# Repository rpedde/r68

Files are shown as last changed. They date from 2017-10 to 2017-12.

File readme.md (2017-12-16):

# r68 std #

This a 68% board, like a tada or sabre.

This supports two layouts:

[Compat](https://goo.gl/bRej9A): This format requires a 1.75u right shift, but retains 1.25u FN keys ([json data](compat.json))
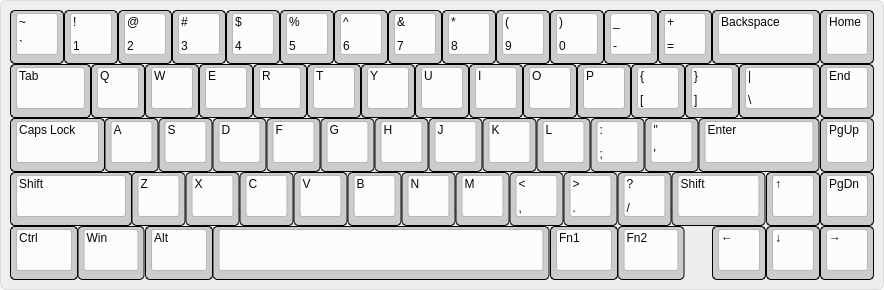
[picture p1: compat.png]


[Narrow](https://goo.gl/9U5wPm): This keeps more meta keys to the right of the space bar, but requires 1u FN keys ([json data](narrow.json))
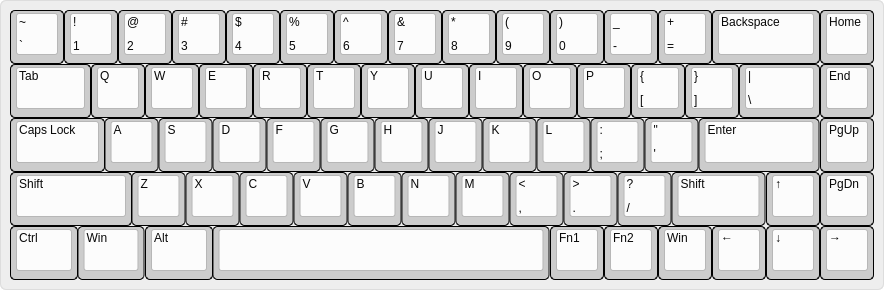
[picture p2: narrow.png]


## Hardware Revisions/Errata ##

* 1.0: Initial version (bad right arrow, not recommended) [gerbers](https://storage.googleapis.com/rpedde-public-gerbers/r68-r1.0.zip)
* 1.1: Fix right arrow, change (ground short on C14) [gerbers](https://storage.googleapis.com/rpedde-public-gerbers/r68-r1.1.zip)
* 1.2: Repour ground (ordered from easyeda, verified working) [gerbers](https://storage.googleapis.com/rpedde-public-gerbers/r68-r1.2.zip)

## License ##

This work is Copyright 2017 Ron Pedde and distributed under the term of the GNU General Public License (version 2 or later).

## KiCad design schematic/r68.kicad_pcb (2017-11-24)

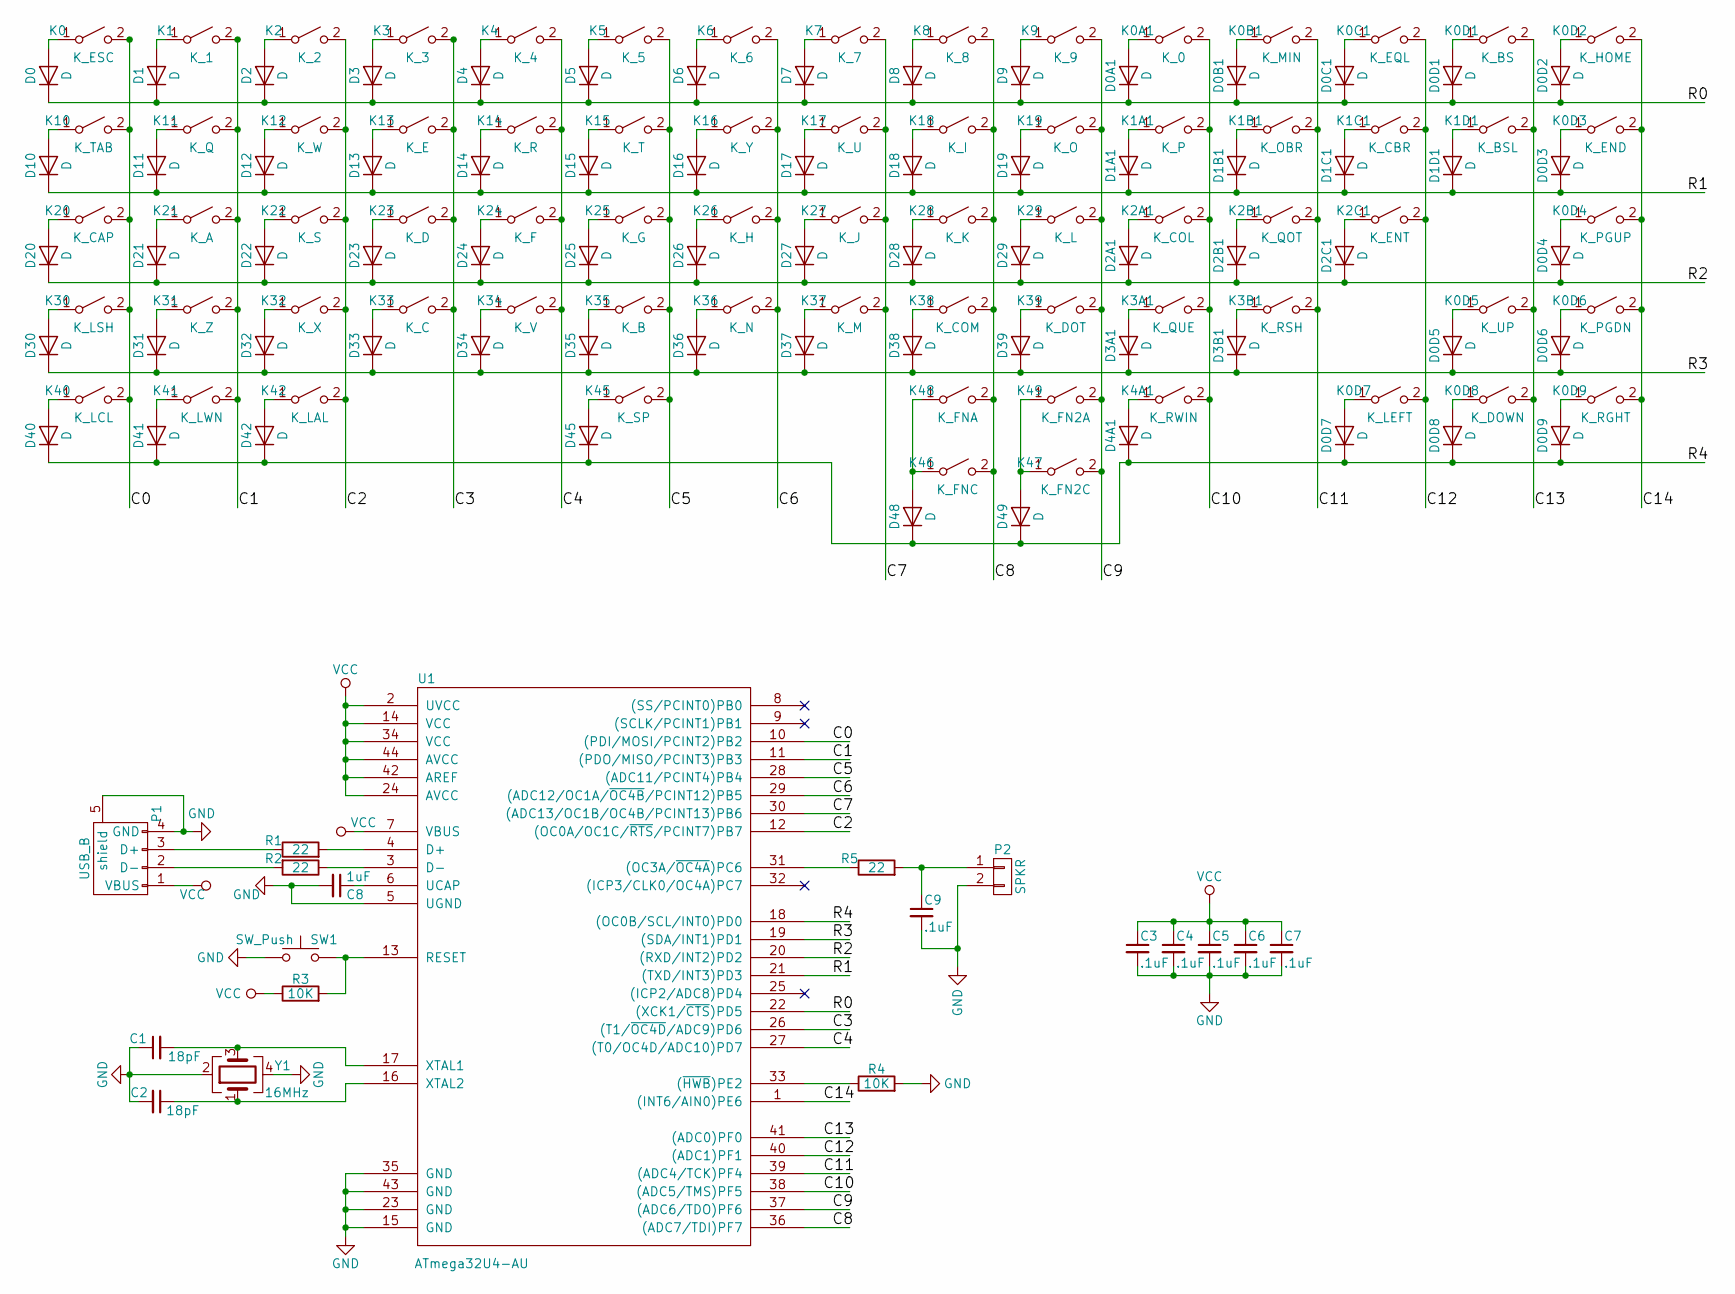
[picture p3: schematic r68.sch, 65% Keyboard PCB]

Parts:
C1, C2: 18pF; C_0805
C3, C4, C5, C6, C7, C9: .1uF; C_0805
C8: 1uF; C_0805
D0, D0A1, D0B1, D0C1, D0D1, D0D2, D0D3, D0D4, D0D5, D0D6, D0D7, D0D8, D0D9, D1, D1A1, D1B1, D1C1, D1D1, D2, D2A1, D2B1, D2C1, D3, D3A1, D3B1, D4, D4A1, D5, D6, D7, D8, D9, D10, D11, D12, D13, D14, D15, D16, D17, D18, D19, D20, D21, D22, D23, D24, D25, D26, D27, D28, D29, D30, D31, D32, D33, D34, D35, D36, D37, D38, D39, D40, D41, D42, D45, D48, D49: D; D_0805
K0: K_ESC; CHERRY_PCB_100H
K0A1: K_0; CHERRY_PCB_100H
K0B1: K_MIN; CHERRY_PCB_100H
K0C1: K_EQL; CHERRY_PCB_100H
K0D1: K_BS; CHERRY_PCB_200H
K0D2: K_HOME; CHERRY_PCB_100H
K0D3: K_END; CHERRY_PCB_100H
K0D4: K_PGUP; CHERRY_PCB_100H
K0D5: K_UP; CHERRY_PCB_100H
K0D6: K_PGDN; CHERRY_PCB_100H
K0D7: K_LEFT; CHERRY_PCB_100H
K0D8: K_DOWN; CHERRY_PCB_100H
K0D9: K_RGHT; CHERRY_PCB_100H
K1: K_1; CHERRY_PCB_100H
K1A1: K_P; CHERRY_PCB_100H
K1B1: K_OBR; CHERRY_PCB_100H
K1C1: K_CBR; CHERRY_PCB_100H
K1D1: K_BSL; CHERRY_PCB_150H
K2: K_2; CHERRY_PCB_100H
K2A1: K_COL; CHERRY_PCB_100H
K2B1: K_QOT; CHERRY_PCB_100H
K2C1: K_ENT; CHERRY_PCB_225H
K3: K_3; CHERRY_PCB_100H
K3A1: K_QUE; CHERRY_PCB_100H
K3B1: K_RSH; CHERRY_PCB_175H
K4: K_4; CHERRY_PCB_100H
K4A1: K_RWIN; CHERRY_PCB_100H
K5: K_5; CHERRY_PCB_100H
K6: K_6; CHERRY_PCB_100H
K7: K_7; CHERRY_PCB_100H
K8: K_8; CHERRY_PCB_100H
K9: K_9; CHERRY_PCB_100H
K10: K_TAB; CHERRY_PCB_150H
K11: K_Q; CHERRY_PCB_100H
K12: K_W; CHERRY_PCB_100H
K13: K_E; CHERRY_PCB_100H
K14: K_R; CHERRY_PCB_100H
K15: K_T; CHERRY_PCB_100H
K16: K_Y; CHERRY_PCB_100H
K17: K_U; CHERRY_PCB_100H
K18: K_I; CHERRY_PCB_100H
K19: K_O; CHERRY_PCB_100H
K20: K_CAP; CHERRY_PCB_175H
K21: K_A; CHERRY_PCB_100H
K22: K_S; CHERRY_PCB_100H
K23: K_D; CHERRY_PCB_100H
K24: K_F; CHERRY_PCB_100H
K25: K_G; CHERRY_PCB_100H
K26: K_H; CHERRY_PCB_100H
K27: K_J; CHERRY_PCB_100H
K28: K_K; CHERRY_PCB_100H
K29: K_L; CHERRY_PCB_100H
K30: K_LSH; CHERRY_PCB_225H
K31: K_Z; CHERRY_PCB_100H
K32: K_X; CHERRY_PCB_100H
K33: K_C; CHERRY_PCB_100H
K34: K_V; CHERRY_PCB_100H
K35: K_B; CHERRY_PCB_100H
K36: K_N; CHERRY_PCB_100H
K37: K_M; CHERRY_PCB_100H
K38: K_COM; CHERRY_PCB_100H
K39: K_DOT; CHERRY_PCB_100H
K40: K_LCL; CHERRY_PCB_125H
K41: K_LWN; CHERRY_PCB_125H
K42: K_LAL; CHERRY_PCB_125H
K45: K_SP; CHERRY_PCB_625H
K46: K_FNC; CHERRY_PCB_100H
K47: K_FN2C; CHERRY_PCB_100H
K48: K_FNA; CHERRY_PCB_125H
K49: K_FN2A; CHERRY_PCB_125H
P1: USB_B; USB_Mini-B
P2: SPKR; Pin_Header_Straight_1x02_Pitch2.54mm
R1, R2, R5: 22; R_0805
R3, R4: 10K; R_0805
SW1: SW_Push; SW_SPST_TL3342
U1: ATmega32U4-AU; TQFP-44_10x10mm_Pitch0.8mm
Y1: 16MHz; Crystal_SMD_3225-4pin_3.2x2.5mm

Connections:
/C0: K0.2 (B), K10.2 (B), K20.2 (B), K30.2 (B), K40.2 (B), U1.10 ((PDI/MOSI/PCINT2)PB2)
/C1: K1.2 (B), K11.2 (B), K21.2 (B), K31.2 (B), K41.2 (B), U1.11 ((PDO/MISO/PCINT3)PB3)
/C2: K2.2 (B), K12.2 (B), K22.2 (B), K32.2 (B), K42.2 (B), U1.12 ((OC0A/OC1C/~RTS~/PCINT7)PB7)
/C3: K3.2 (B), K13.2 (B), K23.2 (B), K33.2 (B), U1.26 ((T1/~OC4D~/ADC9)PD6)
/C4: K4.2 (B), K14.2 (B), K24.2 (B), K34.2 (B), U1.27 ((T0/OC4D/ADC10)PD7)
/C5: K5.2 (B), K15.2 (B), K25.2 (B), K35.2 (B), K45.2 (B), U1.28 ((ADC11/PCINT4)PB4)
/C6: K6.2 (B), K16.2 (B), K26.2 (B), K36.2 (B), U1.29 ((ADC12/OC1A/~OC4B~/PCINT12)PB5)
/C7: K7.2 (B), K17.2 (B), K27.2 (B), K37.2 (B), U1.30 ((ADC13/OC1B/OC4B/PCINT13)PB6)
/C8: K8.2 (B), K18.2 (B), K28.2 (B), K38.2 (B), K46.2 (B), K48.2 (B), U1.36 ((ADC7/TDI)PF7)
/C9: K9.2 (B), K19.2 (B), K29.2 (B), K39.2 (B), K47.2 (B), K49.2 (B), U1.37 ((ADC6/TDO)PF6)
/C10: K0A1.2 (B), K1A1.2 (B), K2A1.2 (B), K3A1.2 (B), K4A1.2 (B), U1.38 ((ADC5/TMS)PF5)
/C11: K0B1.2 (B), K1B1.2 (B), K2B1.2 (B), K3B1.2 (B), U1.39 ((ADC4/TCK)PF4)
/C12: K0C1.2 (B), K0D7.2 (B), K1C1.2 (B), K2C1.2 (B), U1.40 ((ADC1)PF1)
/C13: K0D1.2 (B), K0D5.2 (B), K0D8.2 (B), K1D1.2 (B), U1.41 ((ADC0)PF0)
/C14: K0D2.2 (B), K0D3.2 (B), K0D4.2 (B), K0D6.2 (B), K0D9.2 (B), U1.1 ((INT6/AIN0)PE6)
/R0: D0.1 (K), D0A1.1 (K), D0B1.1 (K), D0C1.1 (K), D0D1.1 (K), D0D2.1 (K), D1.1 (K), D2.1 (K), D3.1 (K), D4.1 (K), D5.1 (K), D6.1 (K), D7.1 (K), D8.1 (K), D9.1 (K), U1.22 ((XCK1/~CTS~)PD5)
/R1: D0D3.1 (K), D1A1.1 (K), D1B1.1 (K), D1C1.1 (K), D1D1.1 (K), D10.1 (K), D11.1 (K), D12.1 (K), D13.1 (K), D14.1 (K), D15.1 (K), D16.1 (K), D17.1 (K), D18.1 (K), D19.1 (K), U1.21 ((TXD/INT3)PD3)
/R2: D0D4.1 (K), D2A1.1 (K), D2B1.1 (K), D2C1.1 (K), D20.1 (K), D21.1 (K), D22.1 (K), D23.1 (K), D24.1 (K), D25.1 (K), D26.1 (K), D27.1 (K), D28.1 (K), D29.1 (K), U1.20 ((RXD/INT2)PD2)
/R3: D0D5.1 (K), D0D6.1 (K), D3A1.1 (K), D3B1.1 (K), D30.1 (K), D31.1 (K), D32.1 (K), D33.1 (K), D34.1 (K), D35.1 (K), D36.1 (K), D37.1 (K), D38.1 (K), D39.1 (K), U1.19 ((SDA/INT1)PD1)
/R4: D0D7.1 (K), D0D8.1 (K), D0D9.1 (K), D4A1.1 (K), D40.1 (K), D41.1 (K), D42.1 (K), D45.1 (K), D48.1 (K), D49.1 (K), U1.18 ((OC0B/SCL/INT0)PD0)
GND: C1.1, C2.2, C3.2, C4.2, C5.2, C6.2, C7.2, C8.2, C9.2, P1.4 (GND), P1.5 (shield), P2.2, R4.2, SW1.1, U1.5 (UGND), U1.15 (GND), U1.23 (GND), U1.35 (GND), U1.43 (GND), Y1.2, Y1.4
unnamed: C1.2, U1.17 (XTAL1), Y1.3
unnamed: C2.1, U1.16 (XTAL2), Y1.1
unnamed: C8.1, U1.6 (UCAP)
unnamed: C9.1, P2.1, R5.2
unnamed: D0.2 (A), K0.1 (A)
unnamed: D0A1.2 (A), K0A1.1 (A)
unnamed: D0B1.2 (A), K0B1.1 (A)
unnamed: D0C1.2 (A), K0C1.1 (A)
unnamed: D0D1.2 (A), K0D1.1 (A)
unnamed: D0D2.2 (A), K0D2.1 (A)
unnamed: D0D3.2 (A), K0D3.1 (A)
unnamed: D0D4.2 (A), K0D4.1 (A)
unnamed: D0D5.2 (A), K0D5.1 (A)
unnamed: D0D6.2 (A), K0D6.1 (A)
unnamed: D0D7.2 (A), K0D7.1 (A)
unnamed: D0D8.2 (A), K0D8.1 (A)
unnamed: D0D9.2 (A), K0D9.1 (A)
unnamed: D1.2 (A), K1.1 (A)
unnamed: D1A1.2 (A), K1A1.1 (A)
unnamed: D1B1.2 (A), K1B1.1 (A)
unnamed: D1C1.2 (A), K1C1.1 (A)
unnamed: D1D1.2 (A), K1D1.1 (A)
unnamed: D2.2 (A), K2.1 (A)
unnamed: D2A1.2 (A), K2A1.1 (A)
unnamed: D2B1.2 (A), K2B1.1 (A)
unnamed: D2C1.2 (A), K2C1.1 (A)
unnamed: D3.2 (A), K3.1 (A)
unnamed: D3A1.2 (A), K3A1.1 (A)
unnamed: D3B1.2 (A), K3B1.1 (A)
unnamed: D4.2 (A), K4.1 (A)
unnamed: D4A1.2 (A), K4A1.1 (A)
unnamed: D5.2 (A), K5.1 (A)
unnamed: D6.2 (A), K6.1 (A)
unnamed: D7.2 (A), K7.1 (A)
unnamed: D8.2 (A), K8.1 (A)
unnamed: D9.2 (A), K9.1 (A)
unnamed: D10.2 (A), K10.1 (A)
unnamed: D11.2 (A), K11.1 (A)
unnamed: D12.2 (A), K12.1 (A)
unnamed: D13.2 (A), K13.1 (A)
unnamed: D14.2 (A), K14.1 (A)
unnamed: D15.2 (A), K15.1 (A)
unnamed: D16.2 (A), K16.1 (A)
unnamed: D17.2 (A), K17.1 (A)
unnamed: D18.2 (A), K18.1 (A)
unnamed: D19.2 (A), K19.1 (A)
unnamed: D20.2 (A), K20.1 (A)
unnamed: D21.2 (A), K21.1 (A)
unnamed: D22.2 (A), K22.1 (A)
unnamed: D23.2 (A), K23.1 (A)
unnamed: D24.2 (A), K24.1 (A)
unnamed: D25.2 (A), K25.1 (A)
unnamed: D26.2 (A), K26.1 (A)
unnamed: D27.2 (A), K27.1 (A)
unnamed: D28.2 (A), K28.1 (A)
unnamed: D29.2 (A), K29.1 (A)
unnamed: D30.2 (A), K30.1 (A)
unnamed: D31.2 (A), K31.1 (A)
unnamed: D32.2 (A), K32.1 (A)
unnamed: D33.2 (A), K33.1 (A)
unnamed: D34.2 (A), K34.1 (A)
unnamed: D35.2 (A), K35.1 (A)
unnamed: D36.2 (A), K36.1 (A)
unnamed: D37.2 (A), K37.1 (A)
unnamed: D38.2 (A), K38.1 (A)
unnamed: D39.2 (A), K39.1 (A)
unnamed: D40.2 (A), K40.1 (A)
unnamed: D41.2 (A), K41.1 (A)
unnamed: D42.2 (A), K42.1 (A)
unnamed: D45.2 (A), K45.1 (A)
unnamed: D48.2 (A), K46.1 (A), K48.1 (A)
unnamed: D49.2 (A), K47.1 (A), K49.1 (A)
unnamed: P1.2 (D-), R2.2
unnamed: P1.3 (D+), R1.1
unnamed: R1.2, U1.4 (D+)
unnamed: R2.1, U1.3 (D-)
unnamed: R3.2, SW1.2, U1.13 (RESET)
unnamed: R4.1, U1.33 ((~HWB~)PE2)
unnamed: R5.1, U1.31 ((OC3A/~OC4A~)PC6)
VCC: C3.1, C4.1, C5.1, C6.1, C7.1, P1.1 (VBUS), R3.1, U1.2 (UVCC), U1.7 (VBUS), U1.14 (VCC), U1.24 (AVCC), U1.34 (VCC), U1.42 (AREF), U1.44 (AVCC)

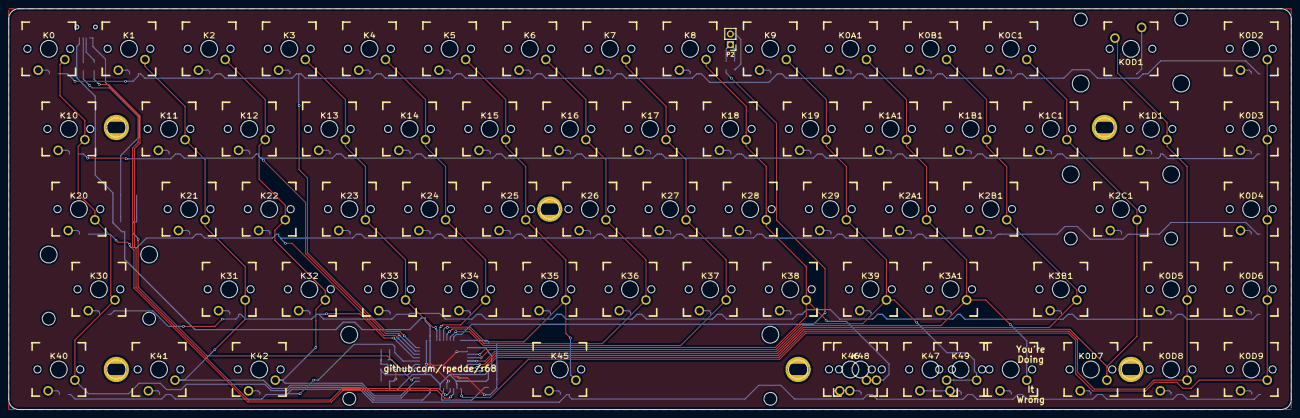
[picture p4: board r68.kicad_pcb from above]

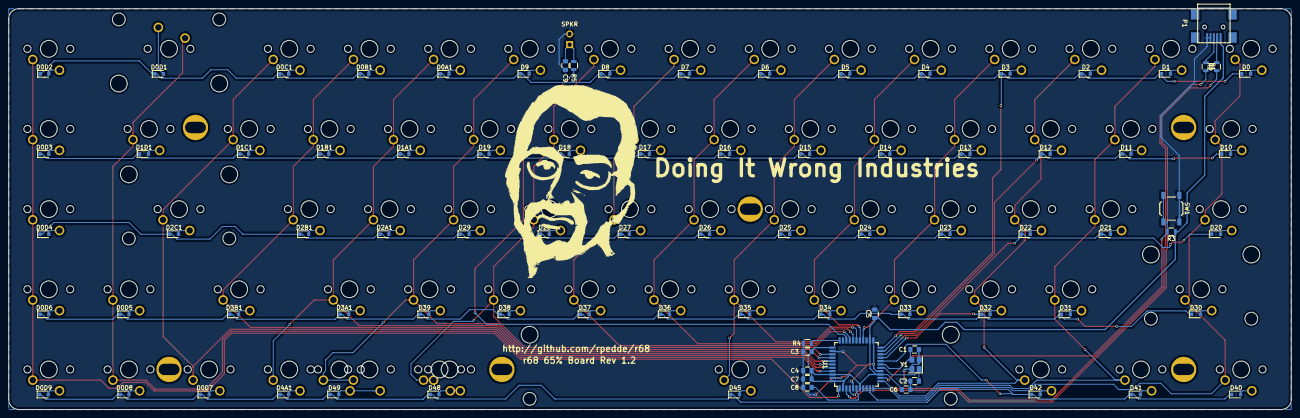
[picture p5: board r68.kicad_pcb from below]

Board: 2 copper layers, 304.8 x 95.3 mm, 157 parts (86 on the bottom side), 101 nets.

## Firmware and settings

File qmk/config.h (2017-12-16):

/*
Copyright 2017 Ron Pedde

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
You should have received a copy of the GNU General Public License
along with this program.  If not, see <http://www.gnu.org/licenses/>.
*/

#ifndef CONFIG_H
#define CONFIG_H

#include "config_common.h"

/* USB Device descriptor parameter */
#define VENDOR_ID       0xFEED
#define PRODUCT_ID      0x6060
#define DEVICE_VER      0x0001
#define MANUFACTURER    Ron Pedde
#define PRODUCT         r68
#define DESCRIPTION     65% keyboard

/* key matrix size */
#define MATRIX_ROWS 5
#define MATRIX_COLS 15

/*
 * Keyboard Matrix Assignments
 *
 * Change this to how you wired your keyboard
 * COLS: AVR pins used for columns, left to right
 * ROWS: AVR pins used for rows, top to bottom
 * DIODE_DIRECTION: COL2ROW = COL = Anode (+), ROW = Cathode (-, marked on diode)
 *                  ROW2COL = ROW = Anode (+), COL = Cathode (-, marked on diode)
 *
*/
#define MATRIX_ROW_PINS { D5, D3, D2, D1, D0 }
#define MATRIX_COL_PINS { B2, B3, B7, D6, D7, B4, B5, B6, F7, F6, F5, F4, F1, F0, E6 }
#define UNUSED_PINS

/* COL2ROW, ROW2COL, or CUSTOM_MATRIX */
#define DIODE_DIRECTION COL2ROW
 
// #define BACKLIGHT_PIN B7
// #define BACKLIGHT_BREATHING
// #define BACKLIGHT_LEVELS 3


/* Debounce reduces chatter (unintended double-presses) - set 0 if debouncing is not needed */
#define DEBOUNCING_DELAY 5

/* define if matrix has ghost (lacks anti-ghosting diodes) */
//#define MATRIX_HAS_GHOST

/* number of backlight levels */

/* Mechanical locking support. Use KC_LCAP, KC_LNUM or KC_LSCR instead in keymap */
#define LOCKING_SUPPORT_ENABLE
/* Locking resynchronize hack */
#define LOCKING_RESYNC_ENABLE

/*
 * Force NKRO
 *
 * Force NKRO (nKey Rollover) to be enabled by default, regardless of the saved
 * state in the bootmagic EEPROM settings. (Note that NKRO must be enabled in the
 * makefile for this to work.)
 *
 * If forced on, NKRO can be disabled via magic key (default = LShift+RShift+N)
 * until the next keyboard reset.
 *
 * NKRO may prevent your keystrokes from being detected in the BIOS, but it is
 * fully operational during normal computer usage.
 *
 * For a less heavy-handed approach, enable NKRO via magic key (LShift+RShift+N)
 * or via bootmagic (hold SPACE+N while plugging in the keyboard). Once set by
 * bootmagic, NKRO mode will always be enabled until it is toggled again during a
 * power-up.
 *
 */
//#define FORCE_NKRO

/*
 * Magic Key Options
 *
 * Magic keys are hotkey commands that allow control over firmware functions of
 * the keyboard. They are best used in combination with the HID Listen program,
 * found here: https://www.pjrc.com/teensy/hid_listen.html
 *
 * The options below allow the magic key functionality to be changed. This is
 * useful if your keyboard/keypad is missing keys and you want magic key support.
 *
 */

/* key combination for magic key command */
#define IS_COMMAND() ( \
    keyboard_report->mods == (MOD_BIT(KC_LSHIFT) | MOD_BIT(KC_RSHIFT)) \
)

/* control how magic key switches layers */
//#define MAGIC_KEY_SWITCH_LAYER_WITH_FKEYS  true
//#define MAGIC_KEY_SWITCH_LAYER_WITH_NKEYS  true
//#define MAGIC_KEY_SWITCH_LAYER_WITH_CUSTOM false

/* override magic key keymap */
//#define MAGIC_KEY_SWITCH_LAYER_WITH_FKEYS
//#define MAGIC_KEY_SWITCH_LAYER_WITH_NKEYS
//#define MAGIC_KEY_SWITCH_LAYER_WITH_CUSTOM
//#define MAGIC_KEY_HELP1          H
//#define MAGIC_KEY_HELP2          SLASH
//#define MAGIC_KEY_DEBUG          D
//#define MAGIC_KEY_DEBUG_MATRIX   X
//#define MAGIC_KEY_DEBUG_KBD      K
//#define MAGIC_KEY_DEBUG_MOUSE    M
//#define MAGIC_KEY_VERSION        V
//#define MAGIC_KEY_STATUS         S
//#define MAGIC_KEY_CONSOLE        C
//#define MAGIC_KEY_LAYER0_ALT1    ESC
//#define MAGIC_KEY_LAYER0_ALT2    GRAVE
//#define MAGIC_KEY_LAYER0         0
//#define MAGIC_KEY_LAYER1         1
//#define MAGIC_KEY_LAYER2         2
//#define MAGIC_KEY_LAYER3         3
//#define MAGIC_KEY_LAYER4         4
//#define MAGIC_KEY_LAYER5         5
//#define MAGIC_KEY_LAYER6         6
//#define MAGIC_KEY_LAYER7         7
//#define MAGIC_KEY_LAYER8         8
//#define MAGIC_KEY_LAYER9         9
//#define MAGIC_KEY_BOOTLOADER     PAUSE
//#define MAGIC_KEY_LOCK           CAPS
//#define MAGIC_KEY_EEPROM         E
//#define MAGIC_KEY_NKRO           N
//#define MAGIC_KEY_SLEEP_LED      Z

/*
 * Feature disable options
 *  These options are also useful to firmware size reduction.
 */

/* disable debug print */
//#define NO_DEBUG

/* disable print */
//#define NO_PRINT

/* disable action features */
//#define NO_ACTION_LAYER
//#define NO_ACTION_TAPPING
//#define NO_ACTION_ONESHOT
//#define NO_ACTION_MACRO
//#define NO_ACTION_FUNCTION

/*
 * MIDI options
 */

/* Prevent use of disabled MIDI features in the keymap */
//#define MIDI_ENABLE_STRICT 1

/* enable basic MIDI features:
   - MIDI notes can be sent when in Music mode is on
*/
//#define MIDI_BASIC
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

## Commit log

2017-10-05 initial checkin
    [r68.kicad_pcb, r68.sch]
2017-10-05 route for 68 key
    [r68.kicad_pcb, r68.sch]
2017-10-24 final hole placement and routing
    [r68-B.Cu.gbl, r68-B.Mask.gbs, r68-B.Paste.gbp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]
2017-11-16 Minor fixes
    * fix right arrow that wasn't wired to r4
    * change the diode footprint to 0805
    [r68-B.Cu.gbl, r68-B.Mask.gbs, r68-B.Paste.gbp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]
2017-11-24 fix shorted C14
    [r68-B.Cu.gbl, r68-B.Mask.gbs, r68-B.Paste.gbp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]

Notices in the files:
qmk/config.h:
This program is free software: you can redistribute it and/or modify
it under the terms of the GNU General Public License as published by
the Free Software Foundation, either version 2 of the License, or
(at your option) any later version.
